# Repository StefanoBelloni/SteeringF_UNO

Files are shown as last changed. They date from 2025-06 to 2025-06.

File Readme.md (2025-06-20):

# STEERING F-UNO: SERIAL STEERING WHEEL
This Project is a simple (easy & cheap) Steering Wheel Joystick using **Arduino UNO** (no support for USB protocol).

## Introduction

The idea was to have a minimal (easy and cheap) Game Steering Wheel mainly to play
(on Linux) [Geoff Crammond's Grand Prix 4](https://www.myabandonware.com/game/grand-prix-4-dwu).
The steering wheel and pedals are based on three potentiometers that are used to
encode their postition and angle.
For the comunication with the computer it uses (for now) an **Arduino UNO**, so only
the a serial comunication is available: to simulate a joystick the library [vgamepad](https://pypi.org/project/vgamepad/) is used.

The Game Steering Wheel consists of three main parts:
* steering wheel
* throttle and break pedals
* python driver

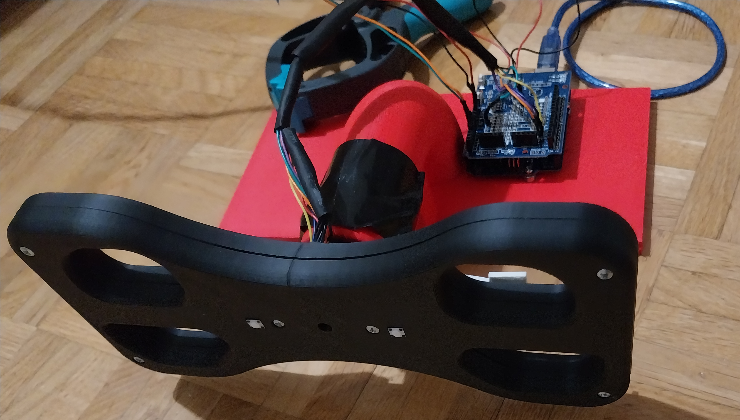
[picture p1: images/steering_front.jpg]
 

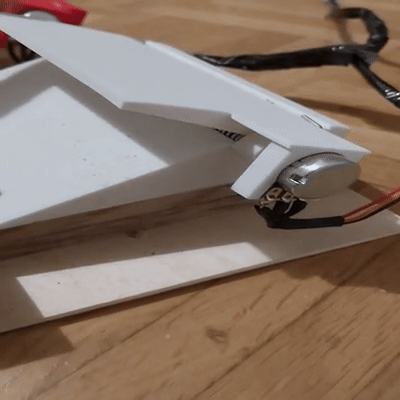
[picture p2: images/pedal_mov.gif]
 

In what follow we are going to describe them in detail.
 
## Components

### Material

#### Steering Wheel and Pedals

For the steering wheel and the pedal, you need to print the models:

* [FreeCAD](https://www.freecad.org/) has been used to design the The Steering Wheel 3D model.

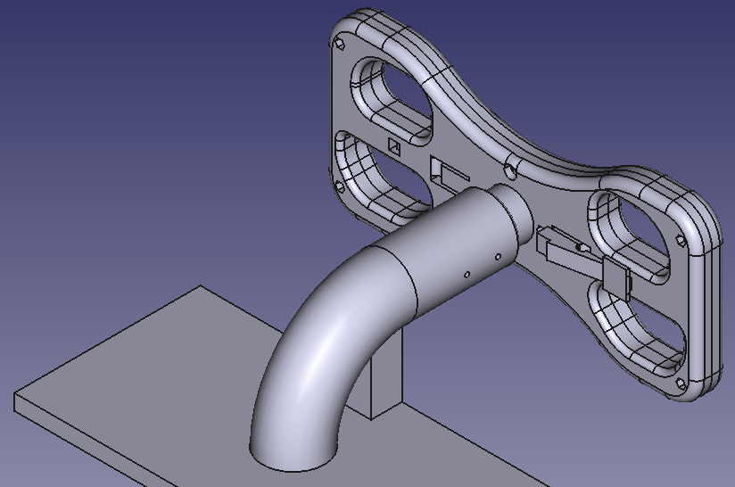
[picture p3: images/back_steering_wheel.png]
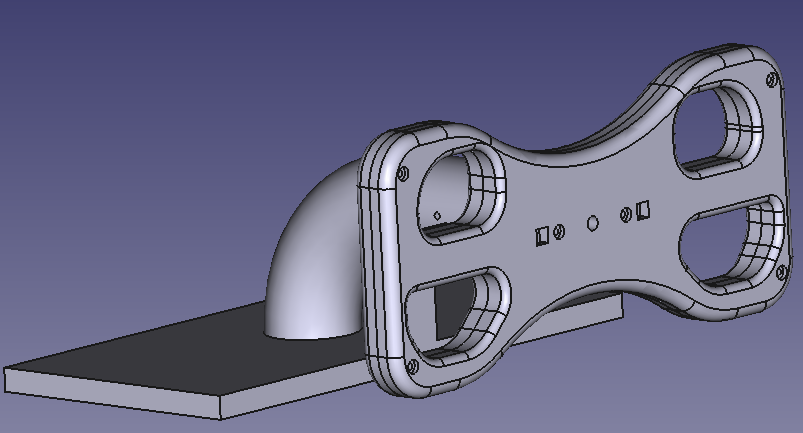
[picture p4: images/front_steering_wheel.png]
 

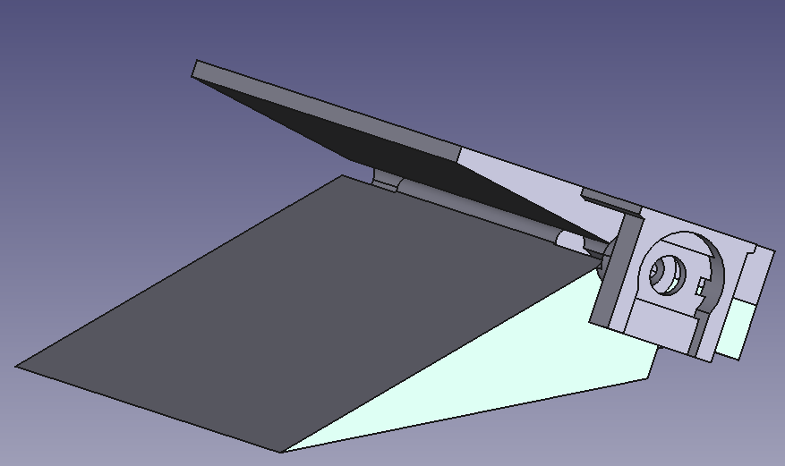
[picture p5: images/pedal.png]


* The _FCStd_ file is in the directoy `./3Dprinter/freeCAD_models`

In order to assemble it, one needs:
* 6 screw `M3x20mm` with a exagonal nut of `6mm`
* 6 springs from clothespin: they are used for the gear (2) and the pedals ( 2 for each)

#### Electronic coomponents
The electronic component consists of only few parts
* Arduino UNO
* 2 potentiometer [Alpha RV16AF-20-15K-B10K RV16AF20KB10KM](https://www.conrad.de/de/p/alpha-rv16af-20-15k-b10k-rv16af20kb10km-dreh-potentiometer-mono-200-mw-10-k-1-st-1694304.html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) for the pedals
      _NOTE_: If you use another type of potentiometer, you need to redesign the pedals
* 1 potentiometer [Weltron 002045038792 WP20CS-08-60F1-10K-20%-LIN](https://www.conrad.de/de/p/weltron-002045038792-wp20cs-08-60f1-10k-20-lin-dreh-potentiometer-mono-0-4-w-10-k-1-st-440891.html) for the steering wheel
* At least 2 buttons [C-TS695 TC-TS695](https://www.conrad.de/de/p/tru-components-tc-ts695-tc-ts695-drucktaster-12-v-dc-tastend-1-st-1589390.html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) for the gear up, gear down.
There are two optional buttons.
      _NOTE_: If you use another type of buttons, you need to redesign the holes for them
* wires

### Cicuit

The cicuit is extremly simple:
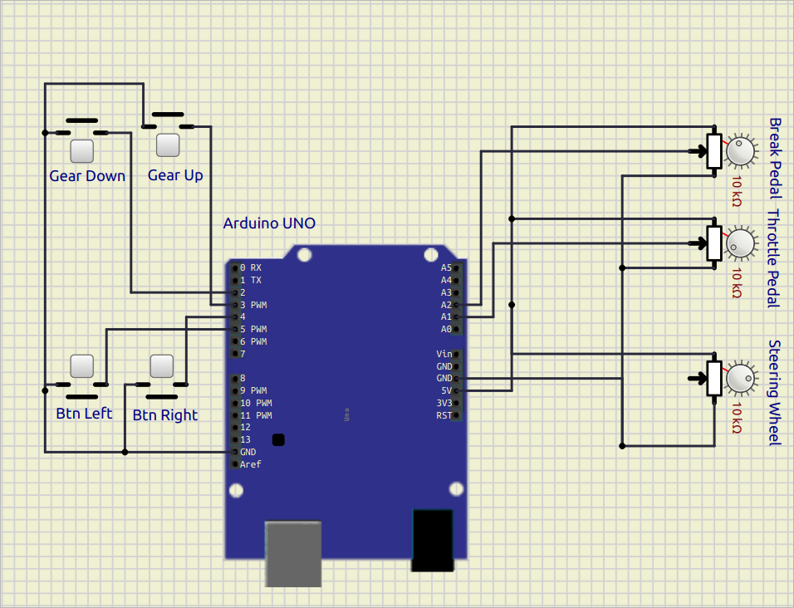
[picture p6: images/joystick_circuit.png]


It consists of just few parts:
* 4 buttons
    * 2 buttons are used to control the gears (UP/DOWN)
    * 2 buttons can be customize
* 3 potentiometers
    * 2 are for the pedals
    * 1 to decode the rotation of the steering wheel
* [Arduino UNO](https://docs.arduino.cc/hardware/uno-rev3/): for the Arduino code see section **Software: Arduino**

* schema and simulation done with [slimul IDE](https://simulide.com/p/) (`simulator/joystick.sim1`)
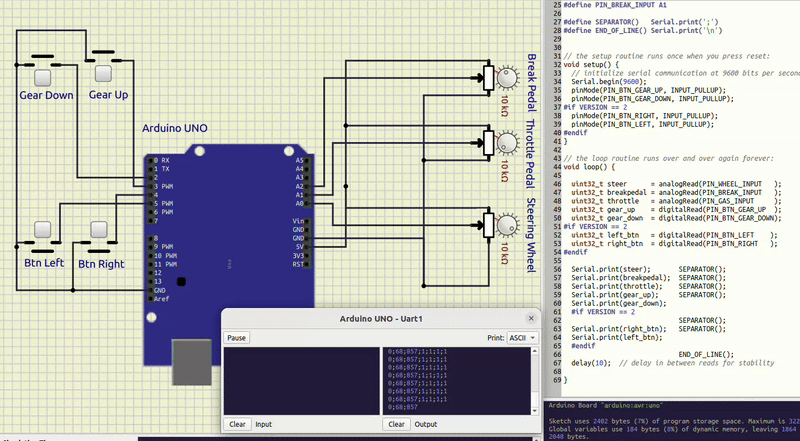
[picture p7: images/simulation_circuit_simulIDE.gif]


### Software

The software consists of two main parts: Arduino and python driver.

#### Arduino

The [arduino sketch](./joystarduino/joystarduino.ino) is extremly simple: it just read the input from the
different pins where potentiometers and buttons are connected and serialize them
to the python driver via the serial port: it is just `;`-separated line of the
different values in a specific order.
There are two type of messages:
* **version 1** consist of only 5 values:

|Position | Component |  Type | pin |
|:---:|:---|:---:|---:|
|1 | steering wheel | analog  | `PIN_WHEEL_INPUT`  |
|2 | break pedal | analog  | `PIN_BREAK_INPUT`  |
|3 | throttle pedal | analog  | `PIN_GAS_INPUT` |
|4 | right back button  | digital | `PIN_BTN_GEAR_UP`  |
|5 | left back button | digital | `PIN_BTN_GEAR_DOWN`|

* **version 2** (`#define VERSION  2`) consist of 2 extra-values:

|Position | Component |  Type | pin |
|:---:|:---|:---:|---:|
|1 | steering wheel | analog  | `PIN_WHEEL_INPUT`  |
|2 | break pedal | analog  | `PIN_BREAK_INPUT`  |
|3 | throttle pedal | analog  | `PIN_GAS_INPUT` |
|4 | right back button  | digital | `PIN_BTN_GEAR_UP`  |
|5 | left back button | digital | `PIN_BTN_GEAR_DOWN`|
|6 | left front button  | digital | `PIN_BTN_LEFT` |
|7 | right front button | digital | `PIN_BTN_RIGHT` |

**NOTE:**  that the Button are initilized in the `pinMode` `INPUT_PULLUP`, so a button press is read as a `LOW` signal, while the button not being pressed is read as `HIGH`.

#### Python Driver

The python driver has 3 component:
* the [runner](virtual_steering_wheel/joystick/runner.py): it identifies the message version and create the corresponding `VirtualJoystic<...>`-object
* The [VirtualJoysticks](virtual_steering_wheel/joystick/vjoy.py):
   * `VirtualJoysticSimple`: minimal joystick with two button (message **version 1**)
   * `VirtualJoysticGP4`: joystick with 4 button (message **version 2**) - the 
        On linux only `GAMEPAD_A` and `GAMEPAD_B` seems to be working: 
        in GP4 keys `x`, `c` are used to look left/right: This joystick simulates these key press with the 2 extra buttons with help of the library `pyautogui`.
* The [ArduinoStateVn](virtual_steering_wheel/joystick/arduino_state.py) store the input from arduino and update the state of the joystick depending of the message version `ArduinoStateV1`, `ArduinoStateV2`

##### Calibration

In order to properly map the values of the potentiometer to proper ranges, the `serial joystick` needs to be calibrated. 

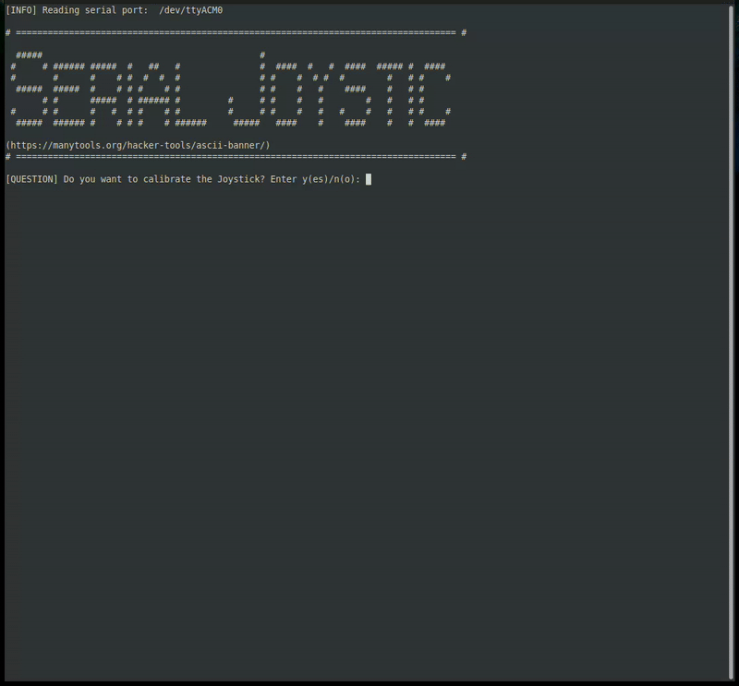
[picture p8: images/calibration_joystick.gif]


At the end of the calibation the ranges can be saved into a file (default is `os.path.expanduser('~/.joystic_configuration')`)

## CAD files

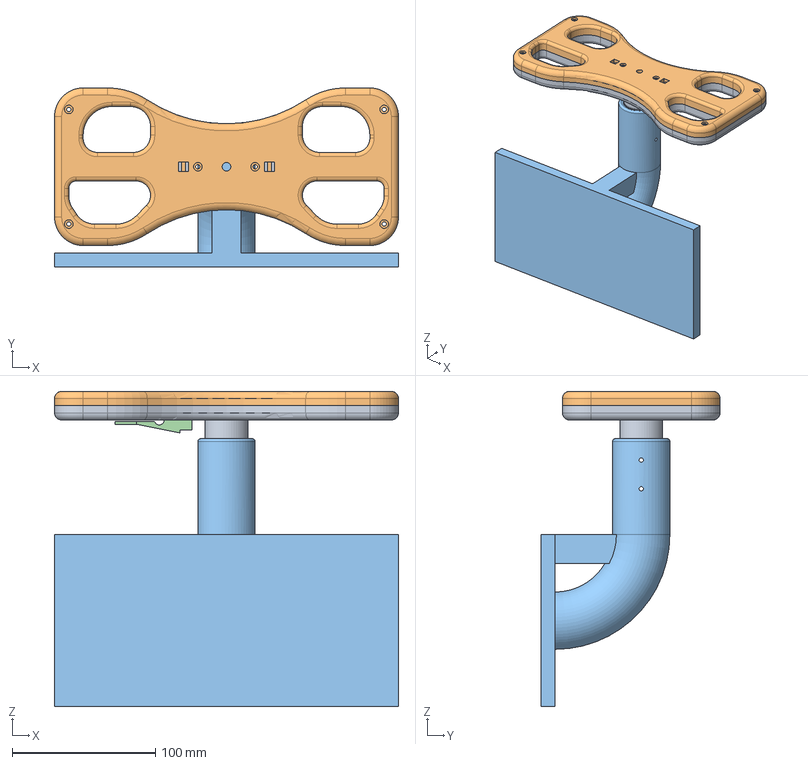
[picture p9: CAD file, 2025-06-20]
3Dprinter/freeCAD_models/003_SteeringWheel.FCStd
240.0 x 125.0 x 220.0 mm
SteeringBottom
SteeringTop
SupportSteeringWheel
GearShiftLeft

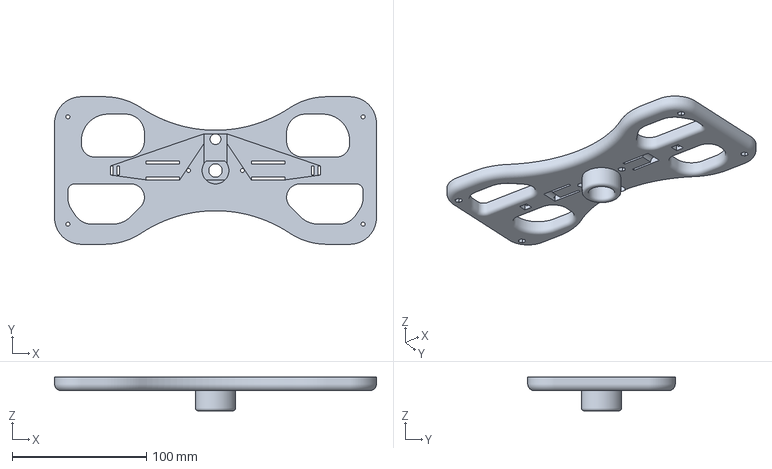
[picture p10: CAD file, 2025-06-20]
3Dprinter/models/003_SteeringWheel-SteeringBottom.3mf
240.0 x 110.0 x 25.0 mm

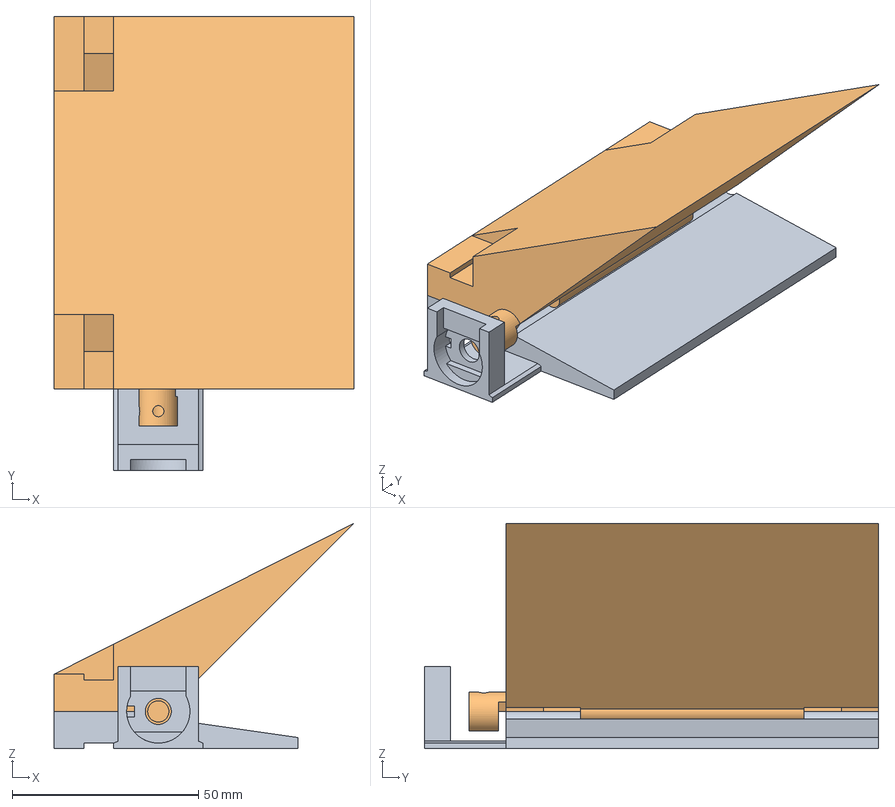
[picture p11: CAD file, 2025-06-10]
3Dprinter/freeCAD_models/000_pedal.FCStd
80.5 x 122.0 x 60.5 mm
PedalInferiorPart
PedalSuperiorPart

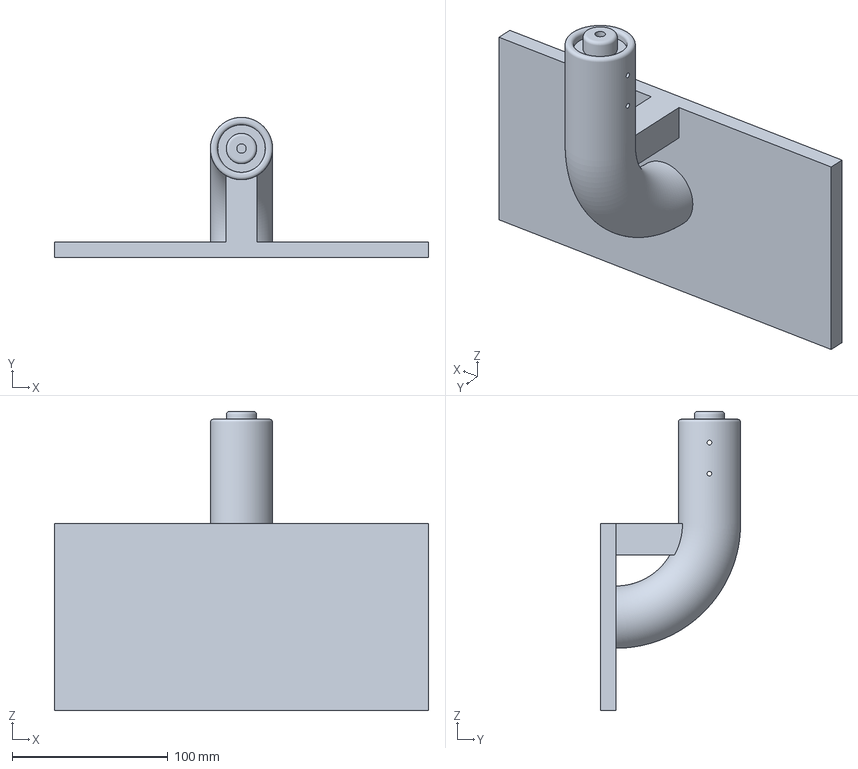
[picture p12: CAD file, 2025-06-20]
3Dprinter/models/003_SteeringWheel-SupportSteeringWheel.3mf
240.0 x 90.0 x 192.0 mm

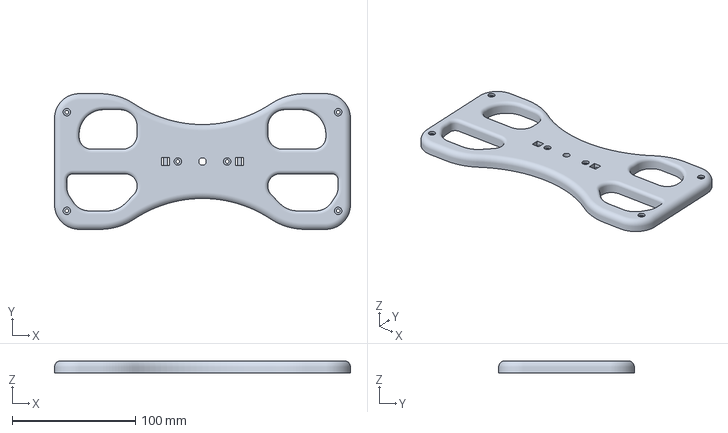
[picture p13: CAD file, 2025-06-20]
3Dprinter/models/003_SteeringWheel-SteeringTop.3mf
240.0 x 110.0 x 10.0 mm

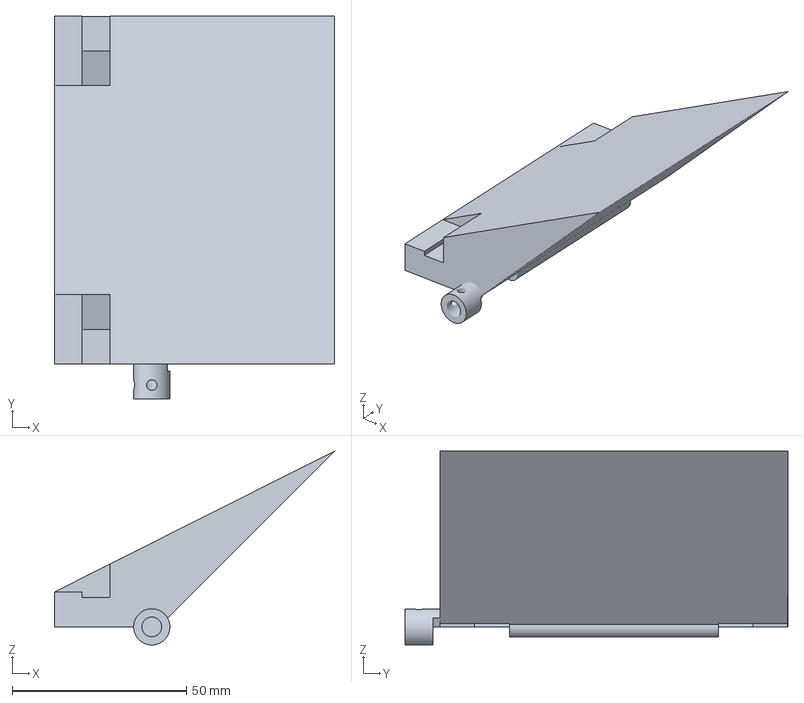
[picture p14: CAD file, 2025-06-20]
3Dprinter/models/000_pedal-PedalSuperiorPart.3mf
80.5 x 110.0 x 55.7 mm

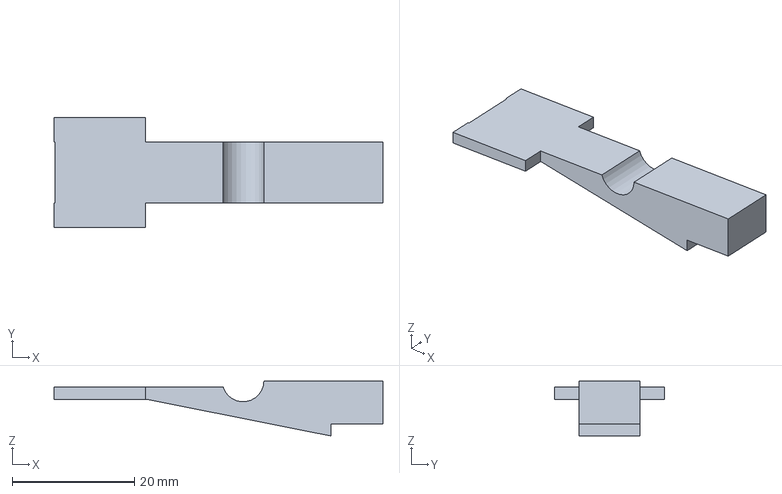
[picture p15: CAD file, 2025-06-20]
3Dprinter/models/003_SteeringWheel-GearShiftLeft.3mf
53.8 x 18.0 x 9.00 mm

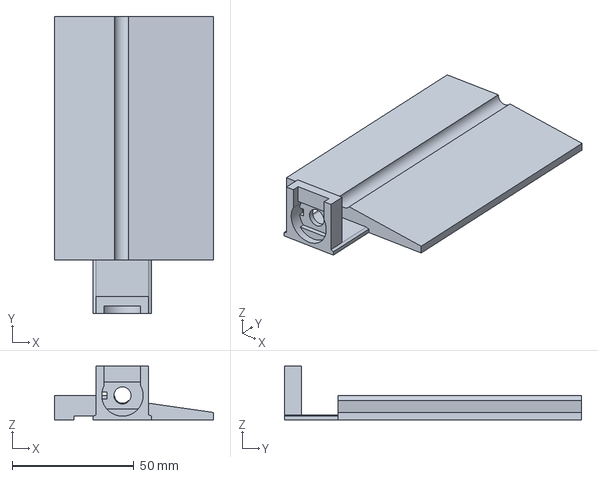
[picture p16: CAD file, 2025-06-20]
3Dprinter/models/000_pedal-PedalInferiorPart.3mf
65.5 x 122.0 x 22.0 mm

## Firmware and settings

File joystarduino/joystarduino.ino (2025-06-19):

/*
  AnalogReadSerial

  Reads an analog input on pin 0, prints the result to the Serial Monitor.
  Graphical representation is available using Serial Plotter (Tools > Serial Plotter menu).
  Attach the center pin of a potentiometer to pin A0, and the outside pins to +5V and ground.

  This example code is in the public domain.

  https://www.arduino.cc/en/Tutorial/BuiltInExamples/AnalogReadSerial
*/

#define VERSION  2

#define PIN_BTN_GEAR_UP   6
#define PIN_BTN_GEAR_DOWN 2

#if VERSION == 2
#   define PIN_BTN_RIGHT 3
#   define PIN_BTN_LEFT  4
#endif

#define PIN_WHEEL_INPUT A0
#define PIN_GAS_INPUT A2
#define PIN_BREAK_INPUT A1

#define SEPARATOR()   Serial.print(';')
#define END_OF_LINE() Serial.print('\n')


// the setup routine runs once when you press reset:
void setup() {
  // initialize serial communication at 9600 bits per second:
  Serial.begin(9600);
  pinMode(PIN_BTN_GEAR_UP, INPUT_PULLUP);
  pinMode(PIN_BTN_GEAR_DOWN, INPUT_PULLUP);
#if VERSION == 2
  pinMode(PIN_BTN_RIGHT, INPUT_PULLUP);
  pinMode(PIN_BTN_LEFT, INPUT_PULLUP);
#endif
}

// the loop routine runs over and over again forever:
void loop() {

  uint32_t steer      = analogRead(PIN_WHEEL_INPUT   );
  uint32_t breakpedal = analogRead(PIN_BREAK_INPUT   );
  uint32_t throttle   = analogRead(PIN_GAS_INPUT     );
  uint32_t gear_up    = digitalRead(PIN_BTN_GEAR_UP  );
  uint32_t gear_down  = digitalRead(PIN_BTN_GEAR_DOWN);
#if VERSION == 2
  uint32_t left_btn   = digitalRead(PIN_BTN_LEFT    );
  uint32_t right_btn  = digitalRead(PIN_BTN_RIGHT   );
#endif

  Serial.print(steer);       SEPARATOR();
  Serial.print(breakpedal);  SEPARATOR();
  Serial.print(throttle);    SEPARATOR();
  Serial.print(gear_up);     SEPARATOR();
  Serial.print(gear_down);   
  #if VERSION == 2
                             SEPARATOR();
  Serial.print(right_btn);   SEPARATOR();
  Serial.print(left_btn);    
  #endif
                             END_OF_LINE();
  delay(10);  // delay in between reads for stability

}

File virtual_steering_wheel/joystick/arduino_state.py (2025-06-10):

import os
import traceback


class LIMITS:
    LIMIT_ACC = 0.05

class _RangeAnalogInput:
    def __init__(self):
        self._min = 0
        self._max = 1023

    @property
    def min(self): return self._min
    @property
    def max(self): return self._max
    
    def load_from_csv_line(self, line): 
        m, M = line.strip().split(';')
        self.set_min(m)
        self.set_max(M)
    def load_from_csv_file(self, f): 
        m, M = f.readline().strip().split(';')
        self.set_min(m)
        self.set_max(M)
    def dump_to_file(self, f): f.write(str(self) + '\n')
    def set_min(self, value): self._min = int(value)
    def set_max(self, value): self._max = int(value)
    def set(self, min_value, max_value): self._min, self._max = int(min_value), int(max_value)

    def __str__(self): return str(self._min) + ';' + str(self._max)

class _AnalogState:
    def __init__(self):
        self._steer = 0
        self._throttle = 0
        self._break = 0

        self._range_steer = _RangeAnalogInput()
        self._range_throttle = _RangeAnalogInput()
        self._range_break = _RangeAnalogInput()
    
    @property
    def steer_raw(self): return self._steer
    @property
    def steer(self): return self._center_value(self._range_steer.min, self._range_steer.max, self._steer)
    @steer.setter
    def steer(self, value): self._steer = value

    @property
    def throttle_row(self): return self._throttle
    @property
    def throttle(self): return self._normalize_value(self._range_throttle.min, self._range_throttle.max, self._throttle)
    @throttle.setter
    def throttle(self, value): self._throttle = value

    @property
    def breakpedal_raw(self): return self._break
    @property
    def breakpedal(self): return -self._normalize_value(self._range_break.min, self._range_break.max, self._break)
    @breakpedal.setter
    def breakpedal(self, value): self._break = value

    @property
    def range_steer(self): return self._range_steer
    @property
    def range_throttle(self): return self._range_throttle
    @property
    def range_break(self): return self._range_break

    @property
    def acceleration(self):
        break_value = self.breakpedal
        if break_value < -LIMITS.LIMIT_ACC:
            return break_value
        throttle = self.throttle
        if throttle > LIMITS.LIMIT_ACC:
            return throttle
        return 0.0

    def dump_config(self, filename):
        with open(filename, 'w') as f:
            for range in [self._range_steer, self._range_throttle, self._range_break]:
                range.dump_to_file(f)

    def load_config(self, filename):
        if not os.path.exists(filename):
            print("™[WARNING] no configuration found! it is advisable to calibrate the joystic")
            return
        with open(filename) as f:
            self._range_steer.load_from_csv_file(f)
            self._range_throttle.load_from_csv_file(f)
            self._range_break.load_from_csv_file(f)

    def update(self, steer, throttle, break_value):
        self._steer = int(steer)
        self._throttle = int(throttle)
        self._break = int(break_value)

    def _center_value(self, min_, max_, x):
        return max(min(1.0, 2 * (x - min_) / (max_ - min_) - 1), -1.0)
    
    def _normalize_value(self, min_, max_, x):
        return max(min(1.0, (x-min_)/(max_-min_)), 0.0)


class _StateFullButton:
    def __init__(self):
        self._previous_value = 1
        self._current_value = 1 
        self._is_pressed = False
        self._has_changed = False

    def update(self, value):
        self._previous_value = self._current_value
        self._current_value = int(value)

        if self._is_pressed and self._previous_value == 0 and self._current_value == 1:
            self._has_changed = True
            self._is_pressed = False
        elif not self._is_pressed and self._previous_value == 1 and self._current_value == 0:
            self._has_changed = True
            self._is_pressed = True
        else:
            self._has_changed = False
    
    @property
    def has_change(self): return self._has_changed
    @property
    def is_pressed(self): return self._is_pressed


class ArduinoStateBase:
    def __init__(self, filename=None):
        self._filename = os.path.expanduser('~/.joystic_configuration') if filename is None else filename
        self._currentAnalogState = _AnalogState()
        self._gear_up = _StateFullButton()
        self._gear_down = _StateFullButton()
        self._btn_left = _StateFullButton()
        self._btn_right = _StateFullButton()

    # ======================================================================== #
    # CONFIGURATIONS
    def get_config(self): return self._filename

    def dump_config(self): self._currentAnalogState.dump_config(self.get_config())

    def load_config(self): self._currentAnalogState.load_config(self.get_config())

    # ======================================================================== #
    # CALIBRATION
    def set_min_steer(self, value):    self._currentAnalogState.range_steer.set_min(value)
    def set_max_steer(self, value):    self._currentAnalogState.range_steer.set_max(value)
    def set_min_throttle(self, value): self._currentAnalogState.range_throttle.set_min(value)
    def set_max_throttle(self, value): self._currentAnalogState.range_throttle.set_max(value)
    def set_min_break(self, value):    self._currentAnalogState.range_break.set_min(value)
    def set_max_break(self, value):    self._currentAnalogState.range_break.set_max(value)

    def set_range_steer(self, min_value, max_value):    self._currentAnalogState.range_steer.set(min_value, max_value)
    def set_range_throttle(self, min_value, max_value): self._currentAnalogState.range_throttle.set(min_value, max_value)
    def set_range_break(self, min_value, max_value):    self._currentAnalogState.range_break.set(min_value, max_value)

    # ======================================================================== #
    # UPDATE
    def update(self, steer, throttle, break_value, gear_up, gear_down, right_btn=1, left_btn=1):
        self._currentAnalogState.update(steer, throttle, break_value)
        self._gear_up.update(gear_up)
        self._gear_down.update(gear_down)
        self._btn_right.update(right_btn)
        self._btn_left.update(left_btn)

    def update_from_line(self, line):
        steer, break_value, throttle_value, gear_up, gear_down, right_btn, left_btn = line.decode('ascii').strip().split(';')
        self.update(steer, throttle_value, break_value, gear_up, gear_down, right_btn, left_btn)
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

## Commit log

2025-06-10 [MINOR] add 3D models
    [000_pedal.FCStd, 003_SteeringWheel.FCStd]
2025-06-20 [ADD] 3D models + pictures
    [000_pedal-PedalInferiorPart.3mf, 000_pedal-PedalSuperiorPart.3mf, 003_SteeringWheel-GearShiftLeft.3mf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]
